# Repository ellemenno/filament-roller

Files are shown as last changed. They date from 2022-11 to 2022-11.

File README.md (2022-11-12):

# filament-roller
smooth rolling spool holder. sized for Ender3 V2.

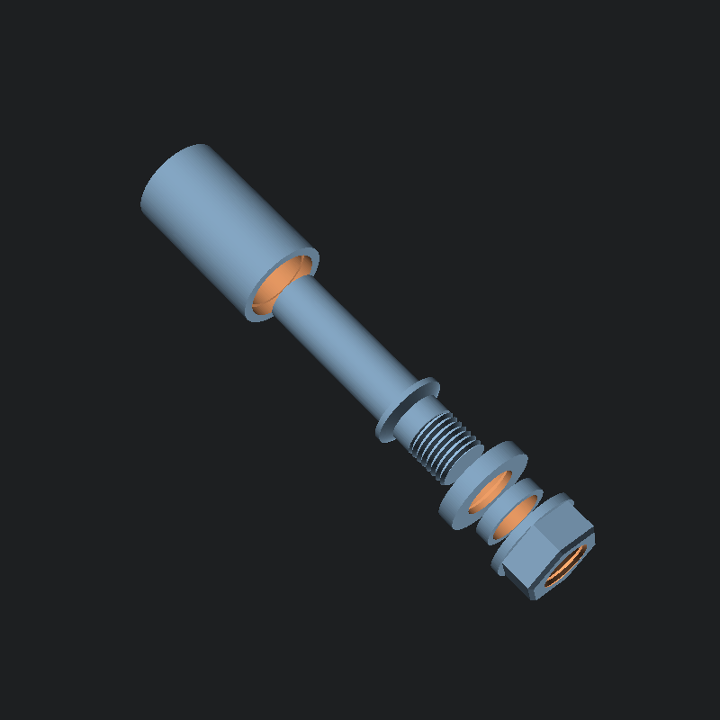
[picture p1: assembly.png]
exploded part diagram


## bill of materials

- 2x 6806 bearings _not included_ (30mm bore ID, 42mm OD, 7mm thickness, 6mm sidewall)
- ~110g PLA+ ~(10h 15min)
  - **roller** (51g, 4h 44min)
  - **arm** (29g, 2h 38min)
  - **washer** (9g, 49min)
  - **spacer** (4g 22min)
  - **flange nut** (16g, 1h 32min)

## printing

- as tested:
  - 0.3mm layer heights and 0.35 layer width from a 0.4mm nozzle
  - slower print speed for threaded items (arm & nut)
  - wall line count of 4
  - 15% gyroid infill
  - concentric top and bottom layers
- **roller** requires supports under lower internal inset (support angle 75°)
- **arm** benefits from a brim for better adhesion and stability
- **flange nut** threads have fewer failures with _Wall Ordering: Inside to Outside_

## automated rendering via OpenSCAD command line

windows (assumes `openscad.com` is on the path)
- `assemby.bat` - renders assembly image
- `parts.bat` - generates STL files for all parts

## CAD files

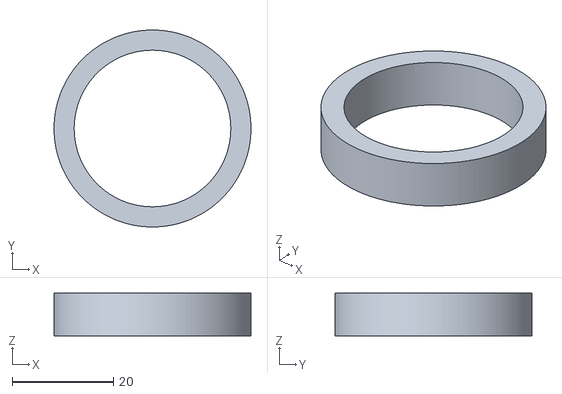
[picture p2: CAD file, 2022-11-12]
stl/spacer.stl
39.0 x 39.0 x 8.50

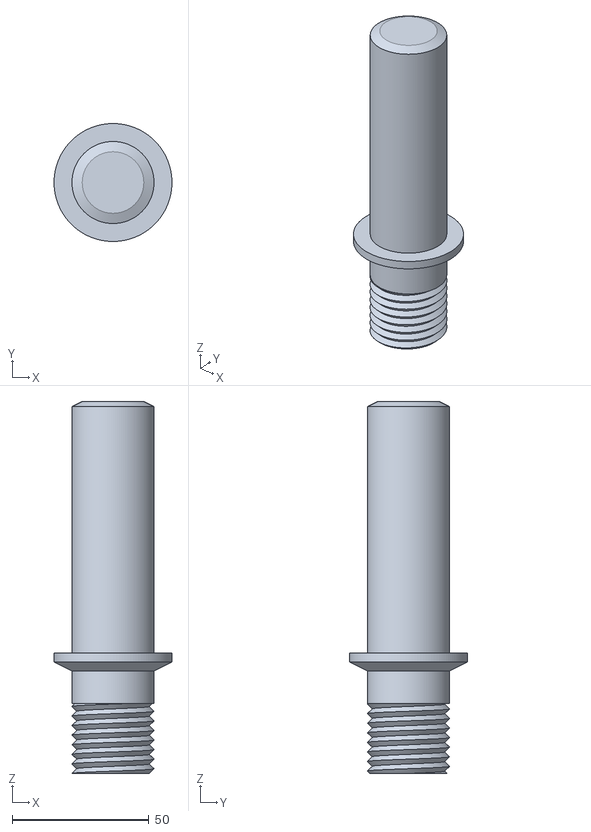
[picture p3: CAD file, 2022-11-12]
stl/arm.stl
43.1 x 43.1 x 136.0

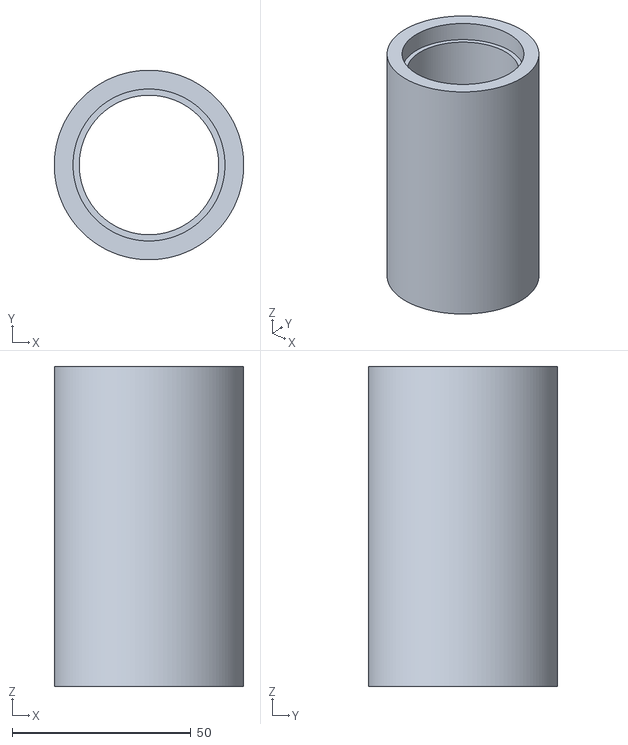
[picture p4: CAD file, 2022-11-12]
stl/roller.stl
53.0 x 53.0 x 89.5

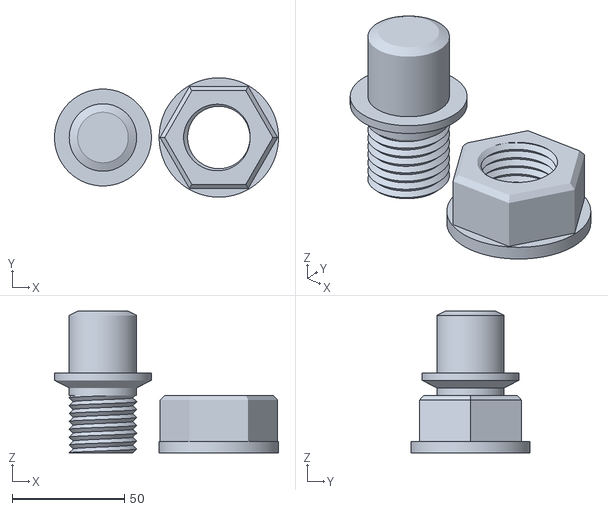
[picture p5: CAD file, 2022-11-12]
stl/test.stl
99.7 x 53.1 x 63.1

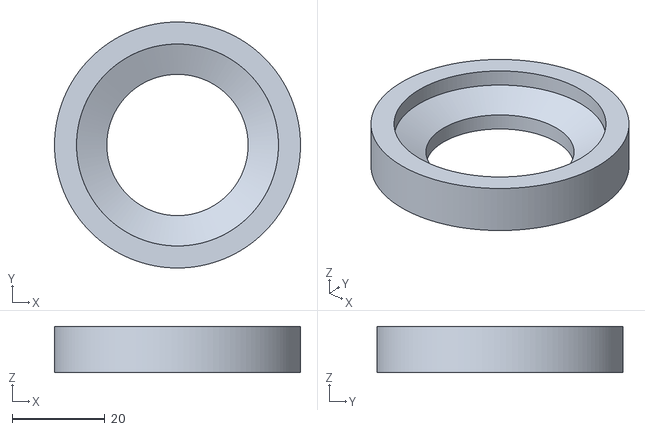
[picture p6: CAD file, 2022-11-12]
stl/washer.stl
53.1 x 53.1 x 10.0

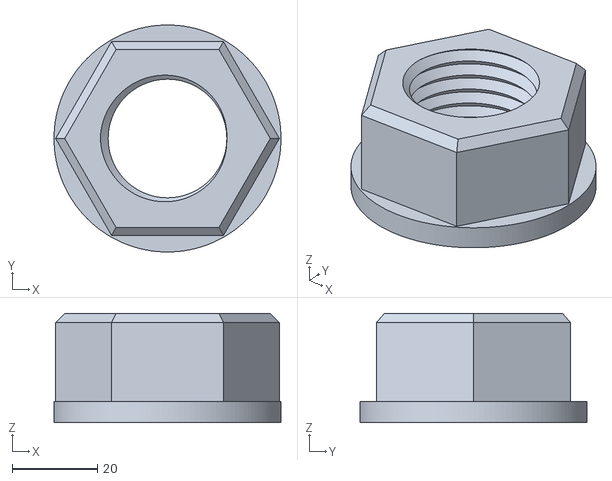
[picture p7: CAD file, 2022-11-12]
stl/nut.stl
53.1 x 53.1 x 25.6

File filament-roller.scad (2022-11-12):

/* filament roller

  - sized to match dimensions of the Creality3 Ender3 roller holder:
    - arm: 30mm OD x 90 mm width
    - bracket: 43mm (1.5mm 40mm 1.5mm) width x 10mm depth x 150mm height
  - fits standard 1kg spool:
    - 54mm ID x 65mm width

  BOM
  - 6806 bearing (30mm bore ID, 42mm OD, 7mm thickness, 6mm sidewall)
  - roller (requires supports under lower internal inset)
  - arm (brim can be helpful)
  - countersunk washer
  - flange nut (for best thread printing, use Wall Ordering: Inside to Outside)
*/

use <threads.scad>
use <lib_filament-roller.scad>

function Bearing6806_OuterDiameter() = 42;
function Bearing6806_InnerDiameter() = 30;
function Bearing6806_Height() = 7;
function Bearing6806_Sidewall() = (Bearing6806_OuterDiameter() - Bearing6806_InnerDiameter()) / 2;
function FilamentSpoolInnerDiameter() = 54;

function RollerOuterDiameter() = FilamentSpoolInnerDiameter(); // outer diameter of roller / inner diameter of spool
function ArmOuterDiameter() = Bearing6806_InnerDiameter(); // outer diameter of arm / inner diameter of bearing
function ArmHeight() = 90; // height/length of arm
function SpacerThickness() = 10 - 1.5;
function SpacerOuterDiameter() = 43 - 1.5*2;

tol = 0.5; // clearance gap between parts
$fn = $preview ? 32 : 128; // number of facets in a 360° arc

module _roller() {
  roller(
    od=FilamentSpoolInnerDiameter(),
    h=ArmHeight(),
    db=Bearing6806_OuterDiameter(),
    hb=Bearing6806_Height(),
    tb=Bearing6806_Sidewall(),
    tolerance=tol
  );
}

module _arm() {
  arm(
    d=Bearing6806_InnerDiameter(),
    h=ArmHeight(),
    spacer_height=SpacerThickness(),
    tolerance=tol
  );
}

module _arm_test() {
  od = Bearing6806_InnerDiameter();
  n = NutThickness(od);
  arm(
    d=od,
    h=n,
    tolerance=tol
  );
}

module _spacer() {
  spacer(
    id=ArmOuterDiameter(),
    od=SpacerOuterDiameter(),
    h=SpacerThickness(),
    tolerance=tol
  );
}

module _washer() {
  id = Bearing6806_InnerDiameter();
  countersunk_washer(
    id=id,
    h=CountersunkWasherThickness(id),
    tolerance=tol
  );
}

module _nut(flange_down=false) {
  tx = flange_down ? [0,0,NutThickness(ArmOuterDiameter())] : [0,0,0];
  rx = flange_down ? [180,0,0] : [0,0,0];
  translate(tx) rotate(rx) {
    flange_nut(
      id=Bearing6806_InnerDiameter(),
      tolerance=tol*1.5
    );
  }
}

module assembly_layout(exploded=true, spacing=10) {
  da = ArmOuterDiameter();
  ha = ArmHeight();
  nt = NutThickness(da);
  st = SpacerThickness();
  kt = CountersunkWasherThickness(da);
  zr = exploded ? nt + kt + ha + da/4 + spacing : nt + st + kt;
  zw = exploded ? -(kt + spacing) : nt + st;
  zs = exploded ? -(st + spacing + kt + spacing) : nt;
  zn = exploded ? -(nt + spacing + st + spacing + kt + spacing) : -tol;
  rotate([70,0,250]) translate([0,0,-(nt+kt)]) {
    translate([0,0,zr]) _roller();
    translate([0,0, 0]) _arm();
    translate([0,0,zw]) _washer();
    translate([0,0,zs]) _spacer();
    translate([0,0,zn]) _nut();
  }
}

module spread_layout(spacing=10) {
  da = ArmOuterDiameter();
  s = HexAcrossCorners(da);
  ss = s + spacing;
  translate([ss/2,s,0]) _roller();
  translate([0,0, 0]) _arm();
  translate([-ss/2,s,0]) _washer();
  translate([-s,0,0]) _spacer();
  translate([ss,0,0]) _nut(flange_down=true);
}

module print_layout(part=0, spacing=10) {
  if (part==1) _roller();
  if (part==2) _arm();
  if (part==3) _washer();
  if (part==4) _spacer();
  if (part==5) _nut(flange_down=true);
  if (part==6) {
    da = ArmOuterDiameter();
    s = HexAcrossCorners(da);
    ss = s/2 + da/2 + spacing;
    _arm_test();
    translate([ss,0,0]) _nut(flange_down=true);
  }
}

module test_layout(spacing=10, cross_section=false) {
  da = ArmOuterDiameter();
  s = HexAcrossCorners(da);
  ss = s/2 + da/2 + spacing;
  nt = NutThickness(da);
  if (cross_section) {
    difference() {
      union() {
        _arm_test();
        _nut(flange_down=false);
      }
      translate([0,0,-nt*0.05]) cube([ss*2, s/2, nt*1.1]); // cross-section
    }
  }
  else {
    union() {
      _arm_test();
      translate([ss,0,0]) _nut(flange_down=true);
    }
  }
}


module main() {
  if (mode=="assembly") assembly_layout(exploded=true);
  if (mode=="print") print_layout(part);
  if (mode=="spread") spread_layout();
  if (mode=="test") test_layout(cross_section=true);
}

mode = "spread"; // ["assembly", "print", "spread", test"]
part = 0; // [1:roller, 2:arm, 3:washer, 4:spacer, 5:nut, 6:test]
main();

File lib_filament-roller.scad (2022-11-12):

use <threads.scad> // uses https://github.com/rcolyer/threads-scad, modified to add chamfer on hex nut


function WasherThickness(id) = id/6;
function CountersunkWasherThickness(id) = id/3;

module washer(id, h=0, tolerance=0.4) {
  wt = h > 0 ? h : WasherThickness(id);
  wd = HexAcrossCorners(id);
  tt = tolerance/2;
  difference() {
    cylinder(h=wt, d=wd);
    translate([0,0,-tt]) cylinder(h=wt+tolerance, d=id+tolerance);
  }
}

module washer_countersink(id, h=0, tolerance=0.4) {
  wt = (h > 0) ? h : WasherThickness(id);
  wd = HexAcrossCorners(id);
  h3 = wt/3;
  tt = tolerance/2;
  d1 = id+tolerance;
  d2 = wd-wt+tolerance;
  e = 0.009;
  union() {
    translate([0,0,h3+h3-e]) cylinder(h=h3+tt+e, d=d2);
    translate([0,0,h3]) cylinder(h=h3, d1=d1, d2=d2);
    translate([0,0,-tt+e]) cylinder(h=h3+tt+e, d=d1);
  }
}

module countersunk_washer(id, h=0, tolerance=0.4) {
  difference() {
    washer(id, h, tolerance=tolerance);
    washer_countersink(id, h, tolerance=tolerance);
  }
}

module flange_nut(id, tolerance=0.4) {
  t = WasherThickness(id);
  n = NutThickness(id);
  w = HexAcrossCorners(id);
  union() {
    HexNut(diameter=id, thickness=n, tooth_angle=45, tolerance=tolerance, bottom_chamfer=true);
    translate([0,0,n-t]) difference() {
      washer(id, tolerance=tolerance);
      translate([0,0,-t/4]) cylinder(h=t*2, d=id+t); // bore
    }
  }
}

module roller(od, h, db, hb, tb, tolerance=0.4) {
  tt = tolerance / 2;
  translate([0,0,-tt]) difference() {
    translate([0,0,tt]) cylinder(h=h-tolerance, d=od-tolerance*2);
    cylinder(h=hb, d=db+tolerance); // bottom bearing bore
    cylinder(h=h, d=db-tb/2); // arm bore
    translate([0,0,h-hb+tt]) cylinder(h=hb, d=db+tolerance); // top bearing bore
  }
}

module arm(d, h, spacer_height=0, tolerance=0.4) {
  wh = CountersunkWasherThickness(d);
  nh = NutThickness(d);
  sh = spacer_height;
  ch = d/16; // cap height
  union() {
    translate([0,0,nh]) {
      translate([0,0,sh]) {
        translate([0,0,h+wh]) cylinder(h=ch, d1=d, d2=d-d/4);
        cylinder(h=h+wh, d=d);
        translate([0,0,0]) washer_countersink(id=d, h=wh, tolerance=0);
      }
      cylinder(h=sh, d=d);
    }
    ScrewThread(outer_diam=d, height=nh, tooth_angle=45, tolerance=tolerance);
  }
}

module spacer(id, od, h, tolerance=0.4) {
  tt = tolerance/2;
  difference() {
    cylinder(h=h, d=od-tolerance*2);
    translate([0,0,-tt]) cylinder(h=h+tolerance, d=id+tolerance*2);
  }
}
